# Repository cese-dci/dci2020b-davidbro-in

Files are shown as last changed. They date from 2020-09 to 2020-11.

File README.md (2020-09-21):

!!! important "Trabajo en progreso"
    Compruebe frecuentemente los cambios. Puedes aprovechar también 
    [**configurando las notificaciones de _release_**](https://docs.gitlab.com/ee/user/profile/notifications.html) 
    para [el repositorio](https://gitlab.com/FreeRTLS/FreeRTLS-Beacon/FreeRTLS-Beacon-Electronics) para estar enterado cuando 
    se realiza un nuevo lanzamiento.

# Bienvenido a FreeRTLS Beacon Electronics
**FreeRTLS Beacon Electronics** es una baliza UWB, _Open Source_, basada en el módulo
[DWM1001C](https://www.decawave.com/product/dwm1001-module/) de [Quorvo (antes Decawave)](https://www.decawave.com/). 

El desarrollo de este proyecto persigue los siguientes objetivos:

- Ser una versión de producción de [DWM1001 _development board_](https://www.decawave.com/product/dwm1001-development-board/)

Al igual que la original placa de desarrollo, posee las siguientes características[@dwm1001dev]:

- Soporte para UWB y _Bluetooth_
- Interfaz J-Link en la placa para grabar y depurar _firmware_
- Alimentación a través de micro USB

[Aquí](docs/requirements/index.md#por-que-hacerlo) se puede leer más sobre la motivación 
por la cuál se empezó con este proyecto.

La [documentación sobre la arquitectura](docs/architecture/index.md) permite entender cómo
está compuesto el sistema y cómo interactuán entre sí sus componentes. Cabe mencionar que 
**FreeRTLS Beacon Electronics** está formado por:

- Módulo [DWM1000C](https://www.decawave.com/product/dwm1001-module/)
- Interfaz J-Link implementada sobre 
[STM32F072CBTx](https://www.st.com/resource/en/datasheet/stm32f072c8.pdf)
- Fuente de alimentación a través de microUSB

### Misión
**FreeRTLS Beacon Electronics** busca permitir la implementación de sistemas de
localización en interiores, como es **FreeRTLS** pero no limitado a él. Es un _beacon_
UWB _open source_ y listo para fabricar o mejorar.

## Novedades
Para la lista completa de cambios visita el [control de cambios](CHANGELOG.md).

## ¿Cómo obtenerlo?
En la sección [_releases_](https://gitlab.com/FreeRTLS/FreeRTLS-Beacon/FreeRTLS-Beacon-Electronics/-/releases) del 
[repositorio](https://gitlab.com/FreeRTLS/FreeRTLS-Beacon/FreeRTLS-Beacon-Electronics) se pueden ver las versiones y el 
procedimiento para obtener **FreeRTLS Beacon Electronics**.

## ¿Cómo usarlo?
### Documentación
En la [documentación detallada](https://freertls.gitlab.io/FreeRTLS-Beacon/FreeRTLS-Beacon-Electronics) se encuentra todo
lo necesario para conocer cómo utilizar **FreeRTLS Beacon Electronics**.

## Contacto
Si quieres contactarme puedes hacerlo a davidmbroin@gmail.com.

## Licencia
Este proyecto usa la siguiente licencia: [CERN Open Hardware Licence Version 2 - Permissive](LICENSE.md).

\bibliography

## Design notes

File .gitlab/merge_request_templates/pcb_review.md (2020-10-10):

<!-- Borrar las secciones que no sean útiles -->

## Esquemático

- [ ] Bibliotecas de símbolos
- [ ] Autores y revisores en el rótulo
- [ ] Título en el rótulo
- [ ] Licencia o copyright en el rótulo
- [ ] Jerarquía
- [ ] Prolijidad conexiones
- [ ] Flujo de izquierda a derecha
- [ ] Tensiones de arriba hacia abajo
- [ ] Referencias de tensión
- [ ] Circuitos integrados con numeración según la funcionalidad y E/S
- [ ] Bloques funcionales bien claros
- [ ] Textos,  leyendas y nombre de net
- [ ] ERC
- [ ] Campos de los componentes

### Comentarios esquemático
<!-- Agregar cualquier comentario que pueda ser importante -->

## Asociación de _footprints_

- [ ] Todos los componentes tienen  huellas asociadas?
- [ ] Tamaño y geometría de las huellas

## Revisión de _footprints_

- [ ] Numeración de los pines (orden y secuencia)
- [ ] Tamaño de los pads
- [ ] Separación entre pads
- [ ] Máscara antisoldante

## PCB
- [ ] Rótulo
- [ ] Notas de grilla y márgen
- [ ] Notas ancho de pistas, vías y agujero de vía
- [ ] Notas fabricante
- [ ] Notas terminación superficial
- [ ] Capas
- [ ] Capas de cobre
- [ ] Borde de PCB
- [ ] Ancho de pistas
- [ ] Tamaño de las vías
- [ ] DRC
- [ ] Distribución de componentes
- [ ] Tamaño del PCB
- [ ] Posición de los componentes
- [ ] Alineación de los componentes
- [ ] Conectores y componentes centrales
- [ ] Ruteo
- [ ] Impedancia controlada
- [ ] Áreas de cobre
- [ ] Áeas de cobre - bordes
- [ ] Distancia al borde
- [ ] Agujeros de sujeción
- [ ] Fiduciales
- [ ] Solder mask y solder paste clearance
- [ ] Serigrafía - Referencias
- [ ] Serigrafía - Nombre y fecha o versión
- [ ] Leyenda DISEÑADO EN xxxx
- [ ] Serigrafía - caras
- [ ] Serigrafía - componentes
- [ ] Serigrafía - Logos
- [ ] Cotas
- [ ] Vista 3D
- [ ] Están todos los modelos 3D dentro del proyecto?

### Comentarios PCB
<!-- Agregar cualquier comentario que pueda ser importante -->

## Prototipo

- [ ] Tiene pines para testing?
- [ ] Tiene leds para las tensiones o señales importantes?
- [ ] Los tamaños de agujeros para los pines tienen la holgura necesaria para que el pin no entre a presión?
- [ ] Tiene el verificador de capas?
- [ ] Tiene cupón de prueba? Hace falta?

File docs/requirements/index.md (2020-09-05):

# FreeRTLS Beacon Electronics
Baliza UWB basada en el módulo [DWM1001C](https://www.decawave.com/product/dwm1001-module/).

---

## Introducción y objetivo
**FreeRTLS Beacon Electronics** es el soporte electrónico para que 
[**FreeRTLS**](http://FreeRTLS.gitlab.io/FreeRTLS) pueda funcionar. Este proyecto
está basado en módulos con 
[tecnología UWB](https://freertls.gitlab.io/FreeRTLS/uwb_and_others.html) y esto 
hace que **FreeRTLS** pueda tener error de apenas algunos centímetros.

## ¿Para quién es?
**FreeRTLS Beacon Electronics** está pensado para formar parte de **FreeRTLS** y ser
instalado en grandes comercios. Sin embargo, cualquier persona que desee implementar
su propio sistema de localización en interiores puede usar este _hardware_ electrónico
y adaptar el _firmware_ para su necesidad puntual.

## ¿Por qué hacerlo?
**FreeRTLS** es motivado por los siguientes puntos:

1. Crear una alternativa a la placa de desarrollo que provee el fabricante con menor 
número de componentes.
1. Crear un proyecto de abierto para que cualquiera lo pueda usar y modificar.

## ¿Qué es?
**FreeRTLS Beacon Electronics** es un circuito electrónico (PCB). Este proyecto contiene
toda la información necesaria para modificar y enviar a fabricar este circuito.

## Perfiles de usuario

- Quien quiera armar su sistema de localización en interiores

## Glosario

- **RTLS (_Real Time Location System_):** Sistema de localización en tiempo real
-  **Balizas (_Beacons_):** Dispositivos electrónicos que transmiten una señal como 
referencia.
- **UWB:** En inglés, *Ultra wideband*. Sistema de comunicaciones de gran ancho 
de banda.
- **PCB:** En inglés, _Printed Circuit Board_. Placa de circuito impreso, es un 
circuito impreso en una placa de material aislante.

### Criterio de liberación (_Release criteria_)
#### Funcionalidad
La idea de este proyecto es ser _plug and play_. Es decir, el usuario no tiene que 
hacer más que conectarlo para usarlo. En caso de querer grabar un nuevo _firmware_,
el usuario dispone de J-Link a través del puerto USB. A su vez, en el mismo puerto 
USB está disponible un puerto serial para monitorear al módulo principal.

Consultar el [índice de características](features/index.md) para más detalle.

#### Usabilidad
El sistema deberá estar auto-documentado. Esto quiere decir que un usuario con manejo 
básico de celulares inteligentes puede lograr ver su ubicación al cabo de unos minutos
de experimentar con **FreeRTLS App**. En caso de estar fuera del alcance de suficientes
**FreeRTLS Beacons**,  algún mensaje informa que su posición no puede ser calculada por 
falta de datos sobre su ubicación.

Sobre la instalación y configuración de **FreeRTLS Beacons**, también aplica el párrafo 
anterior. Si bien acondicionar comercio de grandes dimensiones puede llevar horas o días, 
entender cómo se debe instalar y confifurar cada **FreeRTLS Beacon**, no debe tomar más 
que unos minutos.

#### Confiabilidad
En caso de falla, el sistema debe poder volver a iniciar en menos de 5 minutos.

#### Desempeño/Rendimiento
La ubicación se debe actualizar cada 10 segundos.

#### Soportabilidad (_Software/Hardware_ compatible)
- La **aplicación móvil** debe funcionar en teléfonos celulares con:
    * Android (última versión a la fecha de liberación)
    * *Bluetooth* versión 4.0 o superior
    * Wi-Fi

## Competencia y productos inspiradores

- [Zebra MotionWorks™](https://www.zebra.com/es/es/solutions/intelligent-edge-solutions/rtls.html)

## Notas técnicas
Debido a la posible inexactitud (en el orden de las decenas de metros [@indoor_positioning_compared]) de las tecnologías inalámbricas disponibles en el mercado
actual (Wi-Fi y _Bluetooth_), es posible que sea necesario utilizar nuevas tecnologías 
(como **UWB**). Esto puede implicar que los usuarios, que se quieran localizar con una exactitud del orden de centímetros, necesiten un dispositivo adicional que provea tal característica. Es decir, **no será posible solamente** con el teléfono.

## Características Futuras

- Navegación y rutas en interiores
- Alerta al usuario más cercano
- Acceso web para administradores
- Dispositivo electrónico para seguimiento de objetos

\bibliography

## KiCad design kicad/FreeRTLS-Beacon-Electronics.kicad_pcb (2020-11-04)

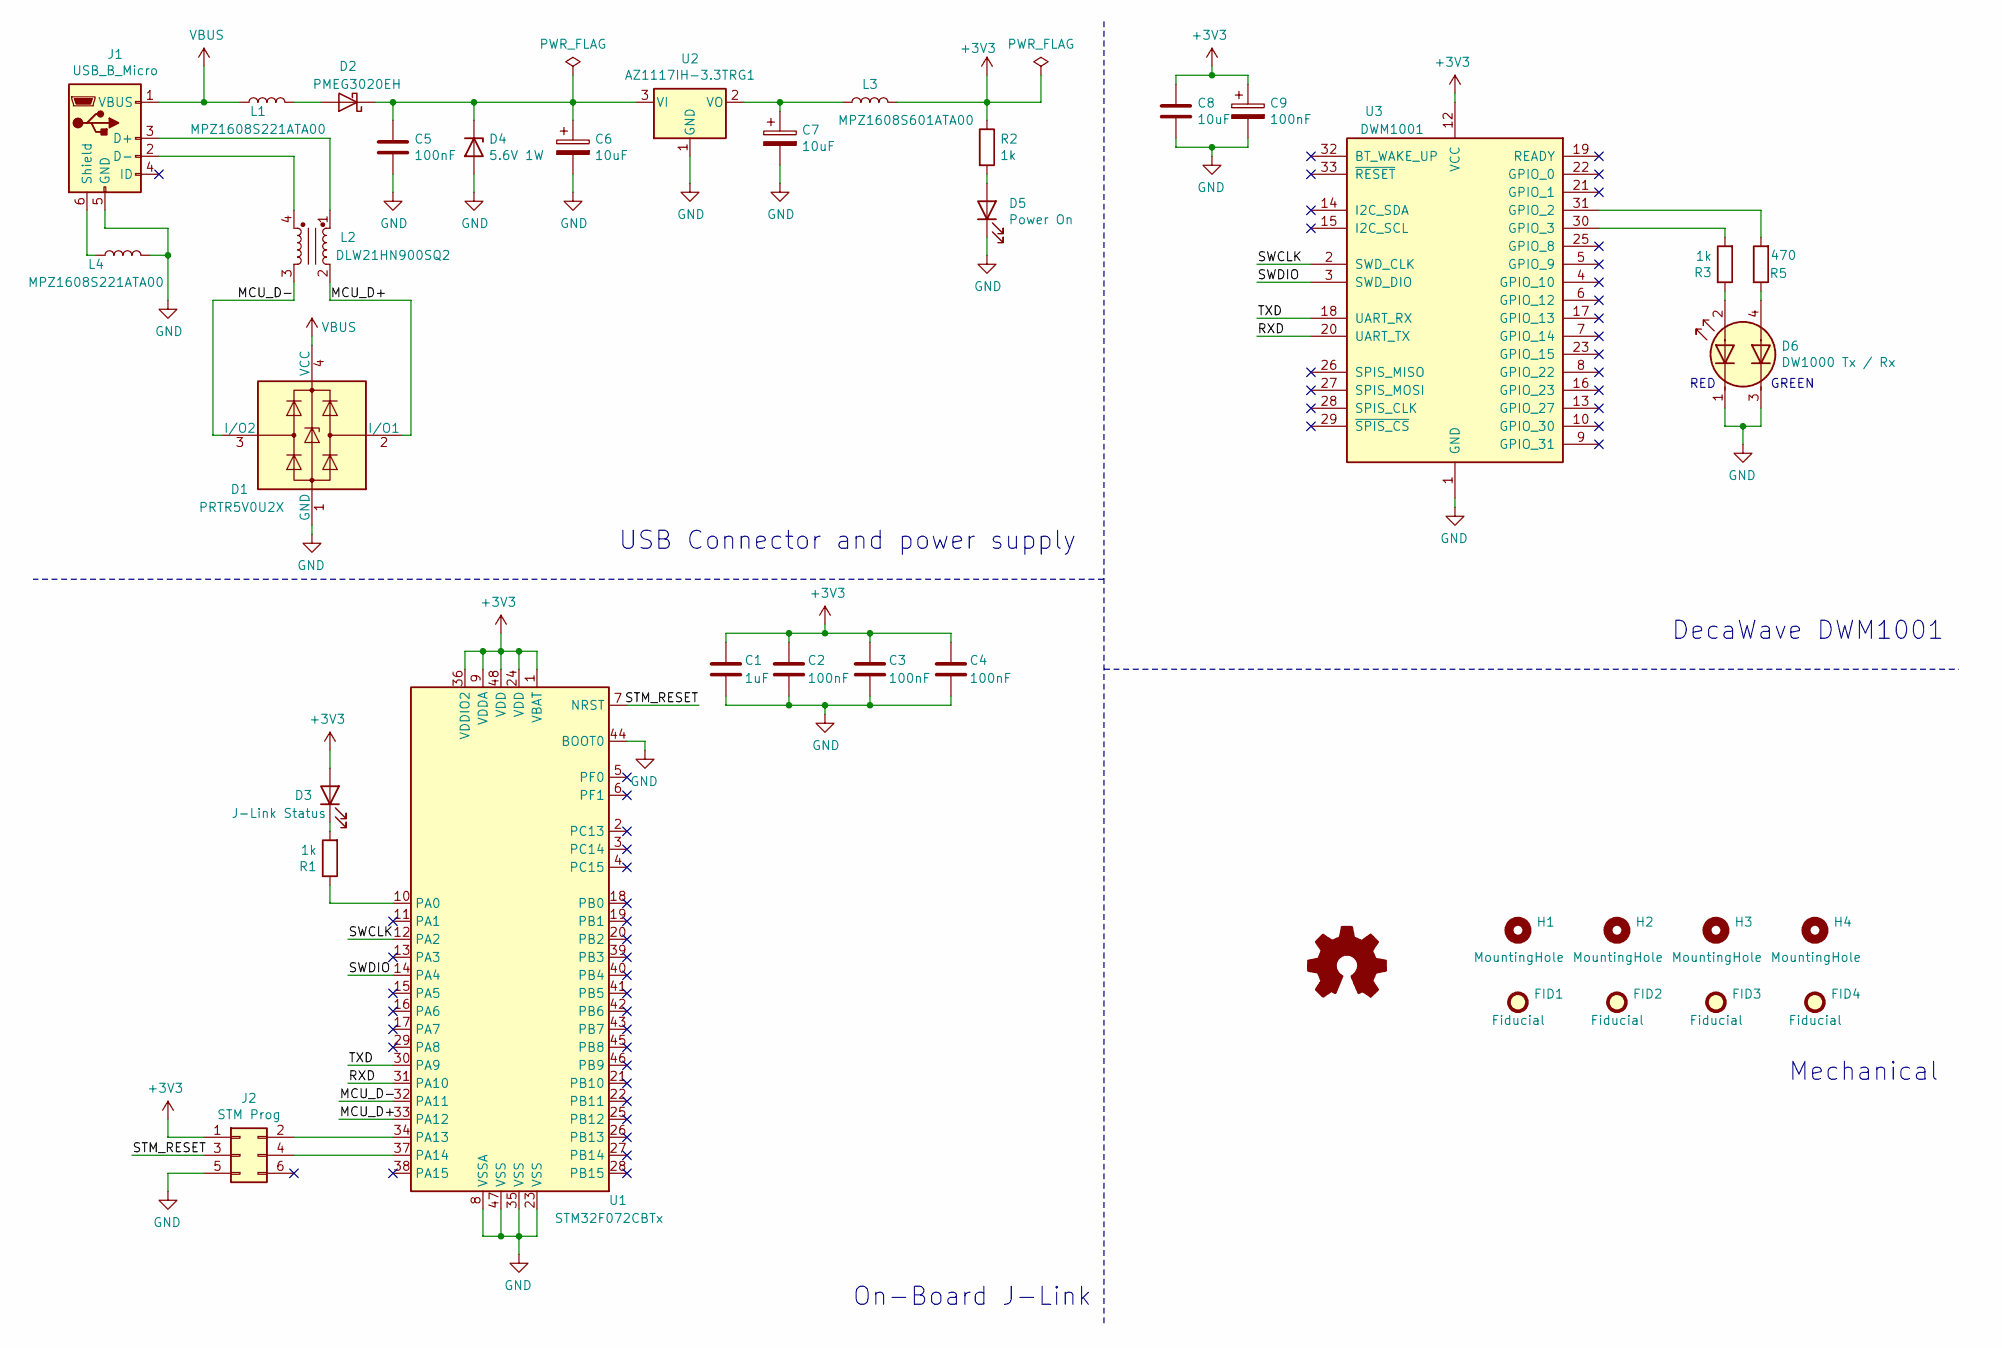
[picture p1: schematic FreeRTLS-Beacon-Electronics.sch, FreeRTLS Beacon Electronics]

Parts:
C1: 1uF; C_0603_1608Metric; MPN CL10A105KP8NNNC; Digi-Key_PN 1276-1182-1-ND
C2, C3, C4, C5, C9: 100nF; C_0603_1608Metric; MPN C0603C104Z3VACTU; Digi-Key_PN 399-1100-1-ND
C6, C7, C8: 10uF; C_0603_1608Metric; MPN C0603X6S100-106MNP; Digi-Key_PN 2679-C0603X6S100-106MNPTR-ND
D1: PRTR5V0U2X; SOT-143; MPN PRTR5V0U2X,215; Digi-Key_PN 1727-3884-1-ND
D2: PMEG3020EH; D_SOD-123F; MPN PMEG3020EH,115; Digi-Key_PN 1727-3873-1-ND
D3: J-Link Status; LED_0603_1608Metric; MPN 150060GS75000; Digi-Key_PN 732-4971-1-ND
D4: 5.6V 1W; D_SOD-123; MPN KDZVTFTR5.6B; Digi-Key_PN KDZVTFTR5.6BCT-ND
D5: Power On; LED_0603_1608Metric; MPN 150060RS75000; Digi-Key_PN 732-4978-1-ND
D6: DW1000 Tx / Rx; LED_L955QEQGC-TR_3.2x2.7mm_P1.7mm; MPN L955QEQGC-TR; Digi-Key_PN 2460-L955QEQGC-TR-ND
FID1, FID2, FID3, FID4: Fiducial; Fiducial_0.5mm_Mask1.5mm
H1, H2, H3, H4: MountingHole; MountingHole_3.2mm_M3
J1: USB_B_Micro; USB_Micro-B_Molex_47346-0001; MPN 0473460001; Digi-Key_PN WM17141CT-ND
J2: STM Prog; Tag-Connect_TC2030-IDC-FP_2x03_P1.27mm_Vertical
L1, L4: MPZ1608S221ATA00; L_0603_1608Metric; MPN MPZ1608S221ATA00; Digi-Key_PN 445-1565-1-ND
L2: DLW21HN900SQ2; FIL_DLW21HN900SQ2L; MPN DLW21HN900SQ2L; Digi-Key_PN 490-1064-1-ND
L3: MPZ1608S601ATA00; L_0603_1608Metric; MPN MPZ1608S601ATA00; Digi-Key_PN 445-2205-1-ND
LOGO1: Logo_Open_Hardware_Small; OSHW-Logo_5.7x6mm_SilkScreen
R1, R2, R3: 1k; R_0603_1608Metric; MPN RC0603JR-071KL; Digi-Key_PN 311-1.0KGRCT-ND
R5: 470; R_0603_1608Metric; MPN RC0603JR-07470RL; Digi-Key_PN 311-470GRCT-ND
U1: STM32F072CBTx; LQFP-48_7x7mm_P0.5mm; MPN STM32F072C8T6; Digi-Key_PN 497-17358-ND
U2: AZ1117IH-3.3TRG1; SOT-223-3_TabPin2; MPN AZ1117IH-3.3TRG1; Digi-Key_PN AZ1117IH-3.3TRG1DICT-ND
U3: DWM1001; DecaWave_DWM1001; MPN DWM1001C; Digi-Key_PN 1479-1004-1-ND

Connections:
+3V3: C1.1, C2.1, C3.1, C4.1, C8.1, C9.1, D3.2 (A), J2.1, L3.2, R2.1, U1.1 (VBAT), U1.9 (VDDA), U1.24 (VDD), U1.36 (VDDIO2), U1.48 (VDD), U3.12 (VCC)
/MCU_D+: D1.2 (I/O1), L2.2, U1.33 (PA12)
/MCU_D-: D1.3 (I/O2), L2.3, U1.32 (PA11)
/RXD: U1.31 (PA10), U3.20 (UART_TX)
/STM_RESET: J2.3, U1.7 (NRST)
/SWCLK: U1.12 (PA2), U3.2 (SWD_CLK)
/SWDIO: U1.14 (PA4), U3.3 (SWD_DIO)
/TXD: U1.30 (PA9), U3.18 (UART_RX)
GND: C1.2, C2.2, C3.2, C4.2, C5.2, C6.2, C7.2, C8.2, C9.2, D1.1 (GND), D4.2 (A), D5.1 (K), D6.1 (A1), D6.3 (A2), J1.5 (GND), J2.5, L4.2, U1.8 (VSSA), U1.23 (VSS), U1.35 (VSS), U1.44 (BOOT0), U1.47 (VSS), U2.1 (GND), U3.1 (GND), U3.11 (GND), U3.24 (GND), U3.34 (GND)
unnamed: C5.1, C6.1, D2.1 (K), D4.1 (K), U2.3 (VI)
unnamed: C7.1, L3.1, U2.2 (VO)
unnamed: D2.2 (A), L1.2
unnamed: D3.1 (K), R1.2
unnamed: D5.2 (A), R2.2
unnamed: D6.2 (K1), R3.1
unnamed: D6.4 (K2), R5.1
unnamed: J1.2 (D-), L2.4
unnamed: J1.3 (D+), L2.1
unnamed: J1.6 (Shield), L4.1
unnamed: J2.2, U1.34 (PA13)
unnamed: J2.4, U1.37 (PA14)
unnamed: R1.1, U1.10 (PA0)
unnamed: R3.2, U3.30 (GPIO_3)
unnamed: R5.2, U3.31 (GPIO_2)
VBUS: D1.4 (VCC), J1.1 (VBUS), L1.1

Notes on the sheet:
USB Connector and power supply
On-Board J-Link
DecaWave DWM1001
GREEN
RED
Mechanical

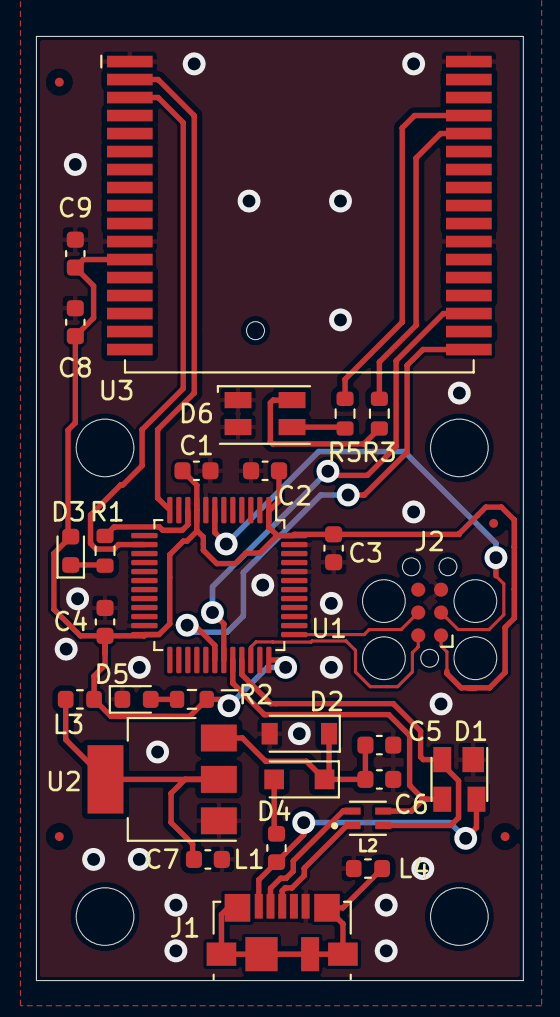
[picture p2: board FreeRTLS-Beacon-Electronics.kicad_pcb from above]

Board: 2 copper layers, 27.1 x 52.5 mm, 37 parts (1 on the bottom side), 25 nets.

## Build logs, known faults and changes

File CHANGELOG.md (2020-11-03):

## 2020.11.3-build.826836119 (2020-11-03)

### Mejoras (CI/CD)

- Agrega PCB Specification !19
## 2020.10.28-build.817990043 (2020-10-28)

### Nuevas (Características)

- Routea PCB !18
## 2020.10.10-build.783535341 (2020-10-10)

### Mejoras (CI/CD)

- Corrige path de templates para merge requests !17
## 2020.10.10-build.783532216 (2020-10-10)

### Mejoras (CI/CD)

- Cambia LED a 3v3 y mejorar textos (tamaño/idioma) !16
## 2020.10.3-build.770811939 (2020-10-03)

### Mejoras (CI/CD)

- Corrige error en ruta de biblioteca apuntada a directorio local !15
## 2020.10.2-build.770586589 (2020-10-02)

### Mejoras (Características)

- Prepara esquemático para revisión !13

### Mejoras (CI/CD)

- Corrige link a índice de características en nav !14
## 2020.10.2-build.770548505 (2020-10-02)

### Mejoras (Características)

- Prepara esquemático para revisión !13
## 2020.9.21-build.749607738 (2020-09-21)

### Mejoras (CI/CD)

- Corrige link de requerimentos en documentación !11
## 2020.9.12-build.734862765 (2020-09-12)

### Mejoras (CI/CD)

- Prueba fix de generación de changelog !10
- Corrige link de inicio !8
# CHANGELOG
## 2020.8.5
- Agrega CI

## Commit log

2020-08-27 Add pcbops to CI config [skip ci]
2020-08-27 Add empty kicad files
    [FreeRTLS-Beacon-Electronics.kicad_pcb, FreeRTLS-Beacon-Electronics.sch]
2020-08-27 Add lib cache and set page settings
    [FreeRTLS-Beacon-Electronics.sch]
2020-08-27 Change revision to WIP!
    [FreeRTLS-Beacon-Electronics.sch]
2020-08-27 Add revision label and board edge
    [FreeRTLS-Beacon-Electronics.kicad_pcb]
2020-08-27 Add page setting
    [FreeRTLS-Beacon-Electronics.kicad_pcb]
2020-08-28 Add trace to test cnc file generation
    [FreeRTLS-Beacon-Electronics.kicad_pcb]
2020-08-28 Add via to test cnc file generation
    [FreeRTLS-Beacon-Electronics.kicad_pcb]
2020-09-01 Add DWM USB and STM to sch
    [FreeRTLS-Beacon-Electronics.sch]
2020-09-02 Add STM32 connections
    [FreeRTLS-Beacon-Electronics.sch]
2020-09-02 Complete USB-STM connections
    [FreeRTLS-Beacon-Electronics.sch]
2020-09-02 Complete DWM1001 section
    [FreeRTLS-Beacon-Electronics.sch]
2020-09-02 Move bom to docs folder
2020-09-02 Embed pdf schematic
2020-10-02 Update due to KiCad update to 5.1.7
2020-10-02 Add author and revisor to sch
    [FreeRTLS-Beacon-Electronics.sch]
2020-10-02 Fix bus usage to delimit components
    [FreeRTLS-Beacon-Electronics.sch]
2020-10-02 Annotate sch
    [FreeRTLS-Beacon-Electronics.sch]
2020-10-02 Add ferrite and change lib to fix ERC errors
    [FreeRTLS-Beacon-Electronics.sch]
2020-10-02 Update values and order power supply
    [FreeRTLS-Beacon-Electronics.sch]
2020-10-02 Add values and order labels
    [FreeRTLS-Beacon-Electronics.sch]
2020-10-02 Fill manufacturer data
    [FreeRTLS-Beacon-Electronics.sch]
2020-10-02 Assign footprints
    [FreeRTLS-Beacon-Electronics.kicad_pcb, FreeRTLS-Beacon-Electronics.sch]
2020-10-02 Add missing footprints and 3D models
2020-10-02 Remove ü and add .DS_Store to gitignore
    [FreeRTLS-Beacon-Electronics.sch]
2020-10-02 Add license info in page settings
    [FreeRTLS-Beacon-Electronics.sch]
2020-10-02 Add mounting holes and fiducials
    [FreeRTLS-Beacon-Electronics.sch]
2020-10-09 Move LED to 3v3 to test whole power
    [FreeRTLS-Beacon-Electronics.sch]
2020-10-09 Enlarge and improve text
    [FreeRTLS-Beacon-Electronics.sch]
2020-10-09 Use value text to indicate usage
    [FreeRTLS-Beacon-Electronics.sch]
2020-10-09 Add dw1000 leds text
    [FreeRTLS-Beacon-Electronics.sch]
2020-10-10 Add pcb review MR template
2020-10-10 Change to test CI
    [FreeRTLS-Beacon-Electronics.sch]
2020-10-15 Place all components and route some
    [FreeRTLS-Beacon-Electronics.kicad_pcb, FreeRTLS-Beacon-Electronics.sch]
2020-10-28 Finish routing
    [FreeRTLS-Beacon-Electronics.kicad_pcb, FreeRTLS-Beacon-Electronics.sch]
2020-11-03 Add PCBWay PCB Specification
    [FreeRTLS-Beacon-Electronics.kicad_pcb]
2020-11-04 Add OSH logo
    [FreeRTLS-Beacon-Electronics.kicad_pcb]
2020-11-04 Hide holes and fiducials refs
    [FreeRTLS-Beacon-Electronics.kicad_pcb]
